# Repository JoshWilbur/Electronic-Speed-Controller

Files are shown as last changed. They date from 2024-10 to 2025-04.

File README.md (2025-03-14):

# Electronic-Speed-Controller

Developers: Amir Seidakhmetov and Joshua Wilbur

This repository contains firmware to drive a 36V Electronic Speed Controller (ESC) for a DC motor. This project has been tested to handle a 3A load without issue. Motor speed is monitored and controlled using a hall effect sensor and PID feedback.

Driver code for the H-Bridge circuit is found in /Core/Src. The files main.c,
H_bridge.c, user_input.c and rpm_feedback.c contain custom code developed
for this project.

Images of the project are found below, along with an operation guide.

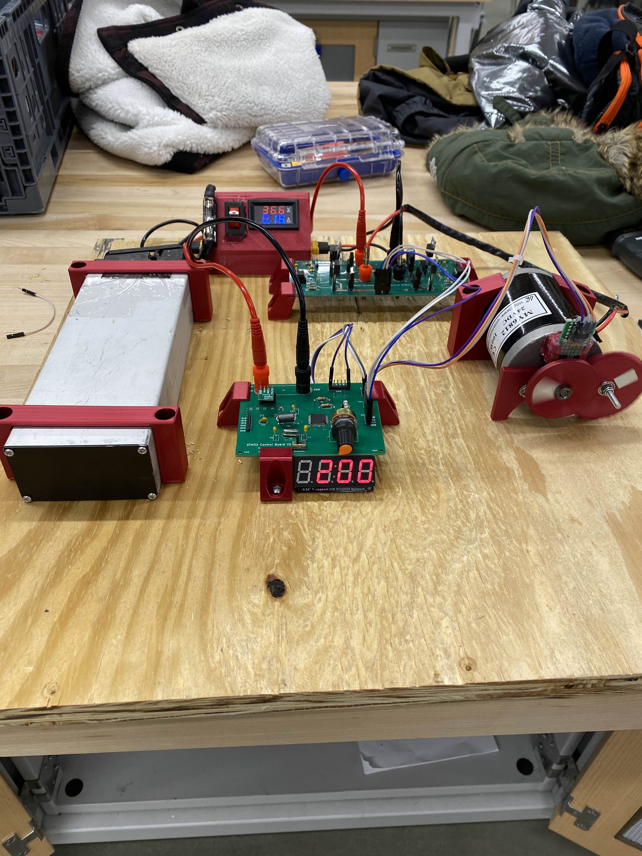
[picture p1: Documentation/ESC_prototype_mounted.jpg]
Prototype December 2024


**Load Testing**
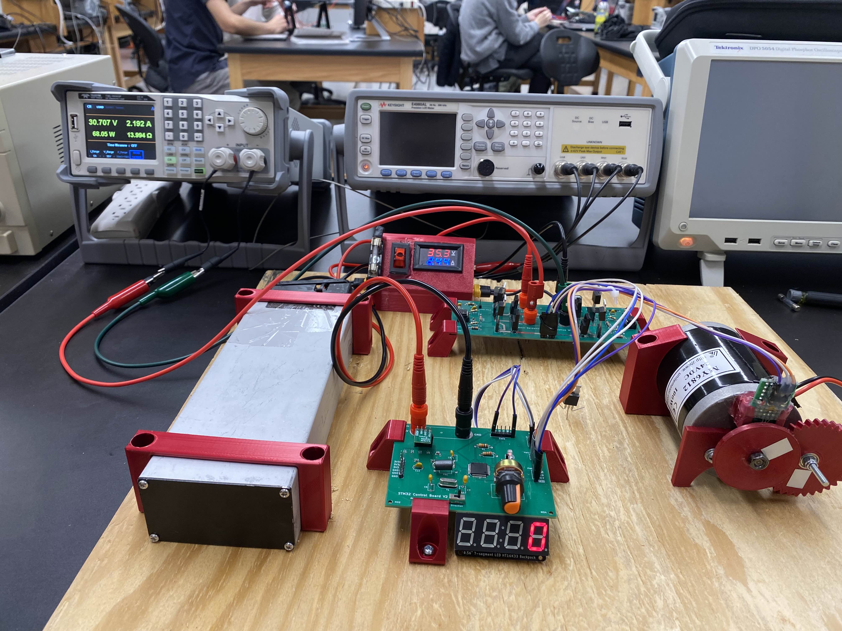
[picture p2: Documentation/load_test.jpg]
Load Test


# Operation Guide

* Construct circuit shown in the latest schematic version with the parts listed in the expense report.
* Optional: Order two PCBs using the files in /H_Bridge_KiCAD and /STM32_KiCAD.
* Program STM32 chip with the code, found in this repository, using SWD.
* Power on circuit and controller.
* For safety, the device starts in an OFF state. Shift the direction switch once to begin operation.
* Use the potentiometer to set a desired speed within the range of 60 to 200 RPM.

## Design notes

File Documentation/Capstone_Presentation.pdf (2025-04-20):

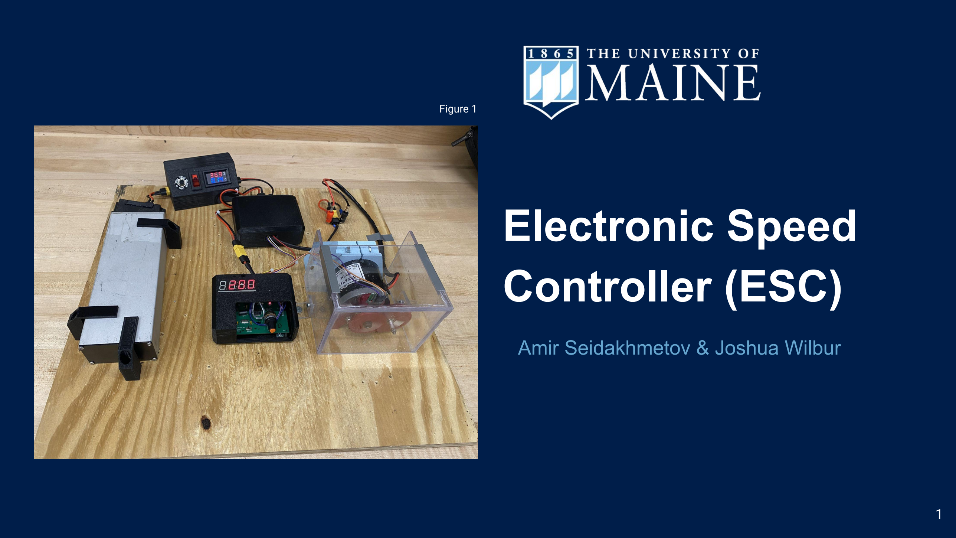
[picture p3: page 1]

# Electronic Speed Controller (ESC)

Amir Seidakhmetov & Joshua Wilbur

Figure 1

# Demonstration

### Presentation Forecast

1. Demonstration
2. Introduction
3. ESC Overview
4. Bootstrap Circuit Design
5. Conclusion
6. Questions

### Purpose of an ESC

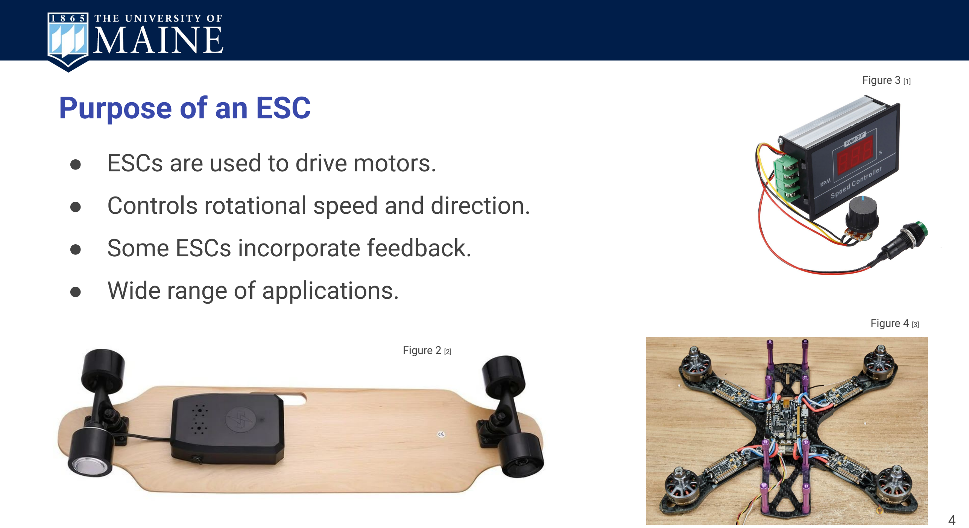
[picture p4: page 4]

- ESCs are used to drive motors.
- Controls rotational speed and direction.
- Some ESCs incorporate feedback.
- Wide range of applications.

Figure 3 [1]

Figure 2 [2]

Figure 4 [3]

### Why Did We Build an ESC?

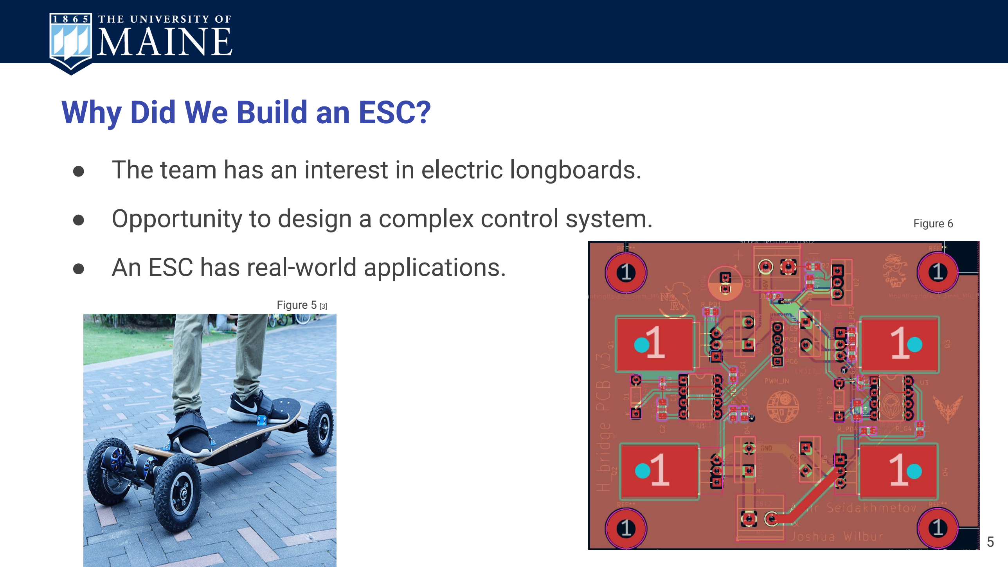
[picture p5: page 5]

- The team has an interest in electric longboards.
- Opportunity to design a complex control system.
- An ESC has real-world applications.

Figure 5 [3]

Figure 6

### Specifications

- H-bridge circuit that can supply at least 2 amps to a motor.
- Closed-loop feedback system to monitor and adjust motor speed.
- Motor rotation speed ranging from 60 RPM ± 5% to 200 RPM ± 5%.

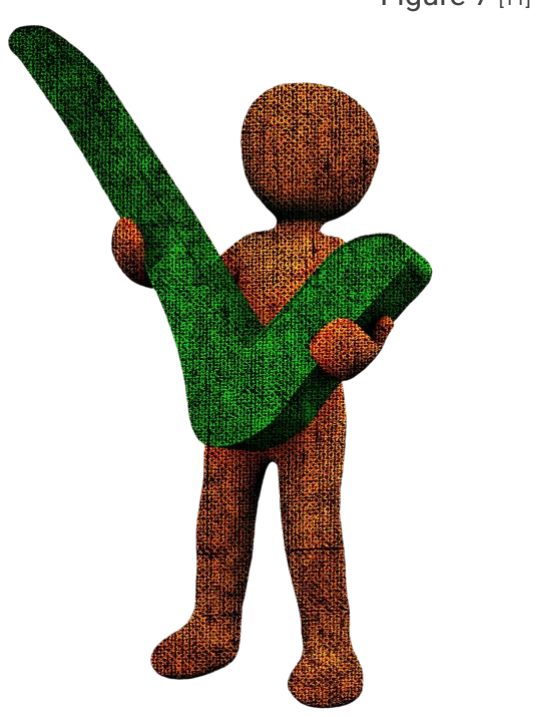
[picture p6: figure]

- Custom PCB designed for the project.
- All specifications were met during design review.

Figure 7 [11]

### Similar Devices

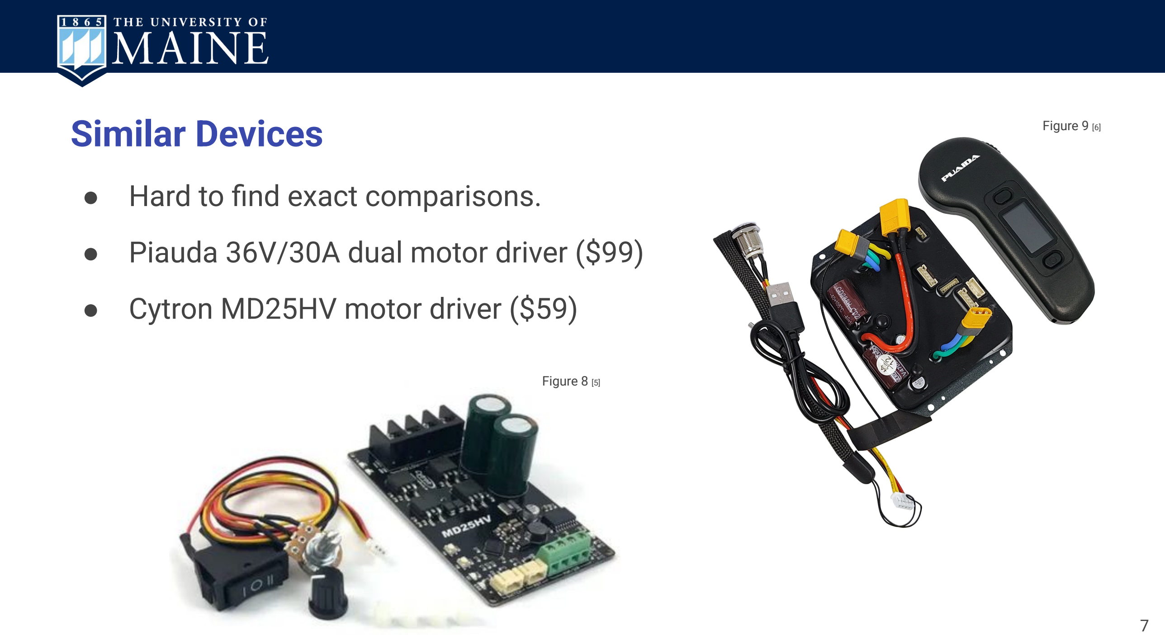
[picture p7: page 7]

- Hard to find exact comparisons.
- Piauda 36V/30A dual motor driver ($99)
- Cytron MD25HV motor driver ($59)

Figure 8 [5]

Figure 9 [6]

# ESC Overview

### Hardware Block Diagram

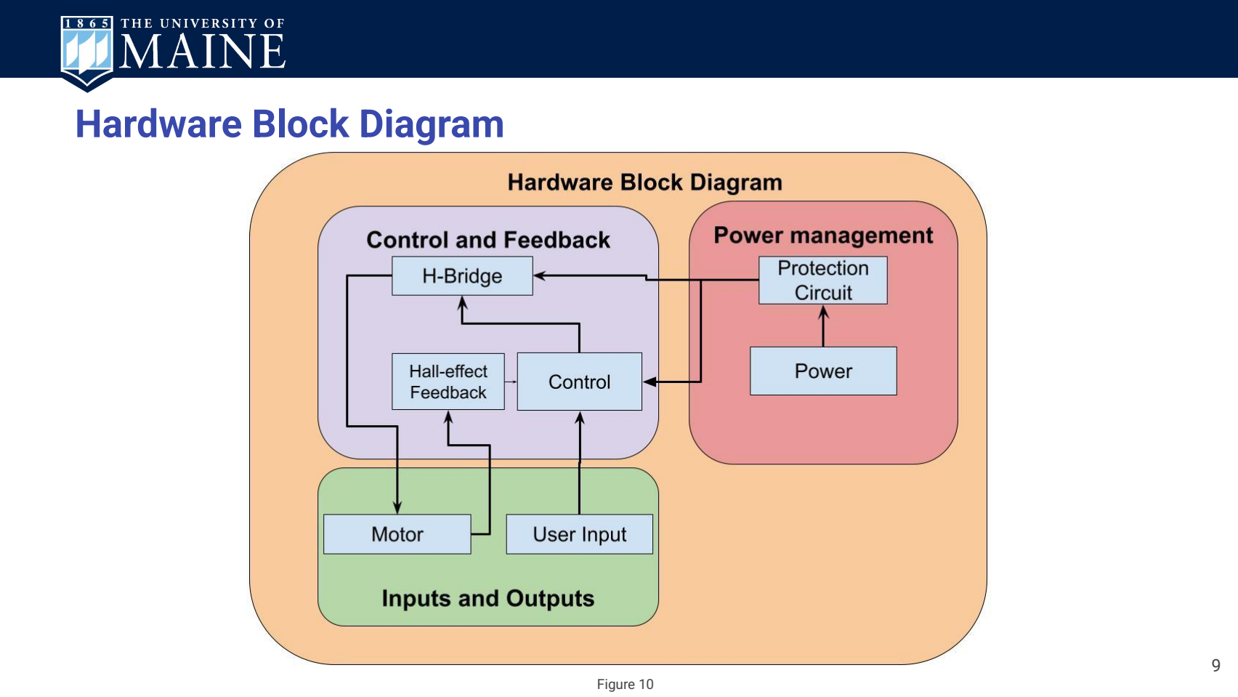
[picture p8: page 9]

Figure 10

### Software Block Diagram

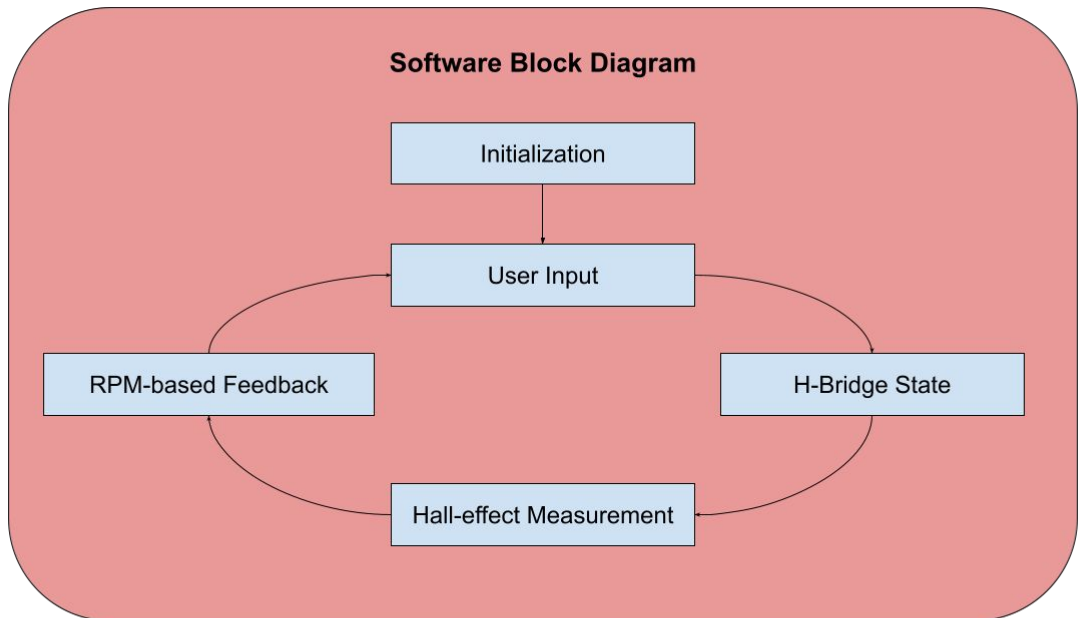
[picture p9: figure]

10 Figure 11

# Bootstrap Circuit Design

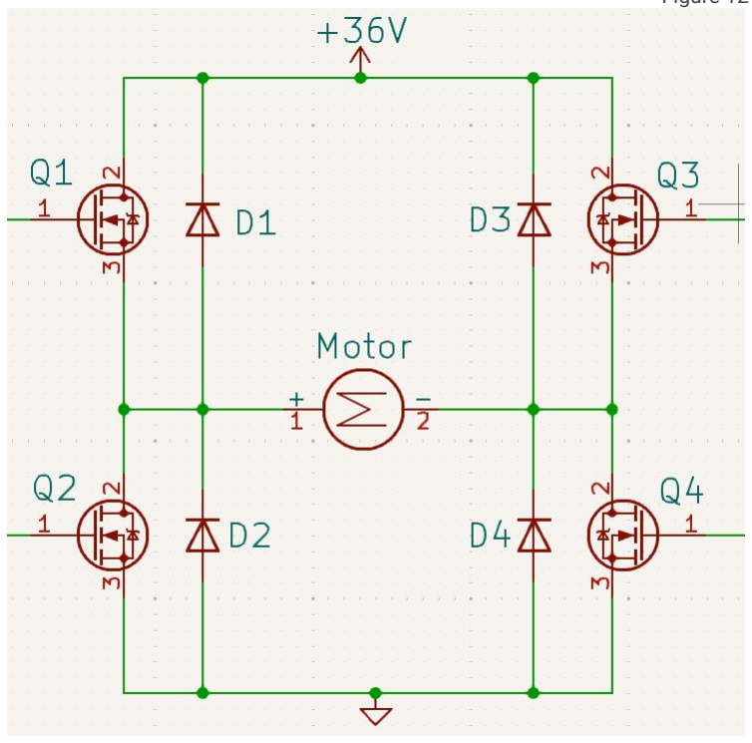
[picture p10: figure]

### Bootstrap Circuit Purpose

- Motor driven by a MOSFET H-bridge.
- MOSFETs require VGS > Vth to turn on
- VDS ≥ (VGS - Vth) for saturation.
- Need a way to boost VG above 36V supply.
- A bootstrap circuit can achieve this.

Figure 12

### Gate Driver Selection

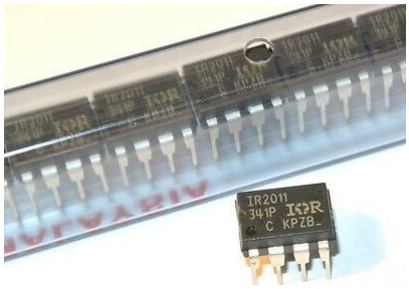
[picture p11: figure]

- Half-bridge driver for N-channel MOSFETs.
- Microcontroller outputs 3.3V signals.
- Gate current requirement.
- IR2011 from Infineon satisfied our needs.

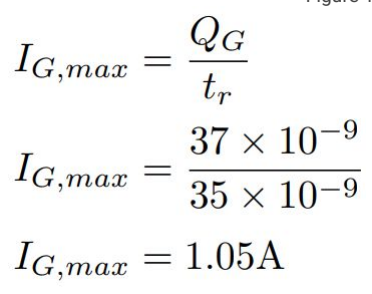
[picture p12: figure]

Figure 13

Figure 14 [7]

### Bootstrap Circuit Components

Figure 15

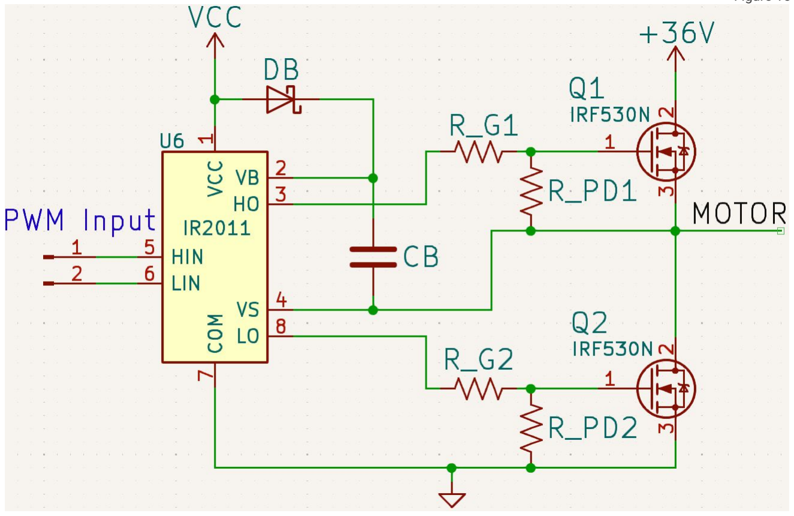
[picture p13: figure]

### Bootstrap Circuit Context

- Gate driver supply voltage (VCC) set to 15V.
- RDS(ON) minimized when VGS is 10V or greater.
- Bootstrap diode: 1N4148

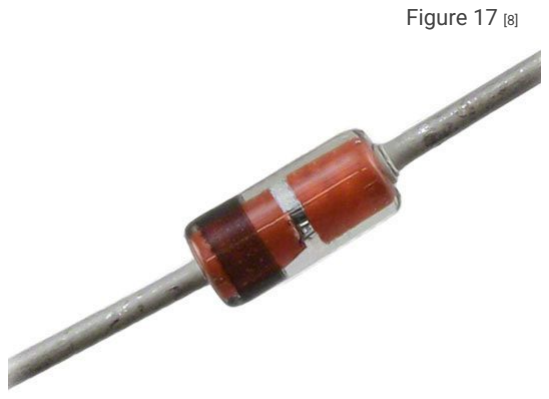
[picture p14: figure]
Figure 17 [8]

- Voltage across CB drops when high-side MOSFET turns on.

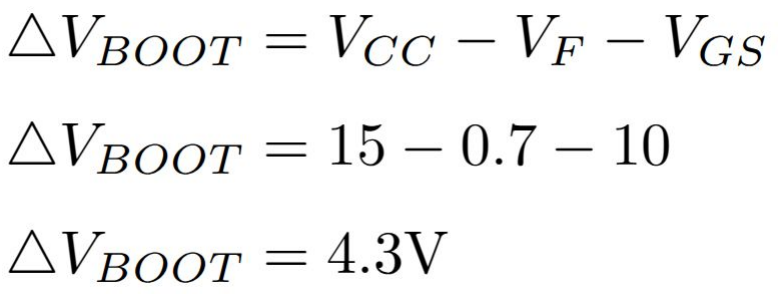
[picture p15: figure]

Figure 16

### Bootstrap Capacitor Calculation

- Value dependant on total charge and allowable voltage drop.

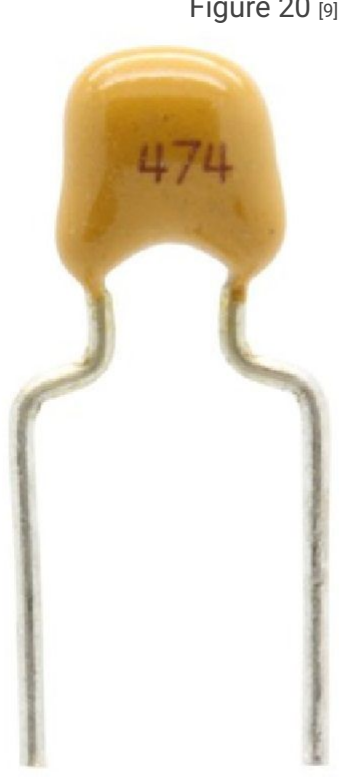
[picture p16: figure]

- Recommended value is at least 10x larger than the minimum.
- The team used a 470nF capacitor.

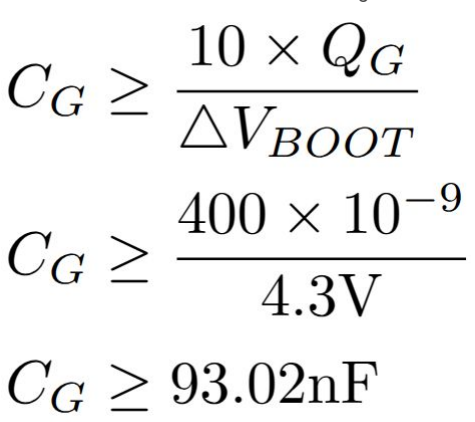
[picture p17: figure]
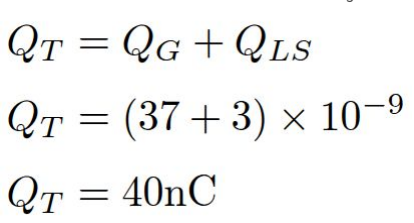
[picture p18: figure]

Figure 18

Figure 19

Figure 20 [9]

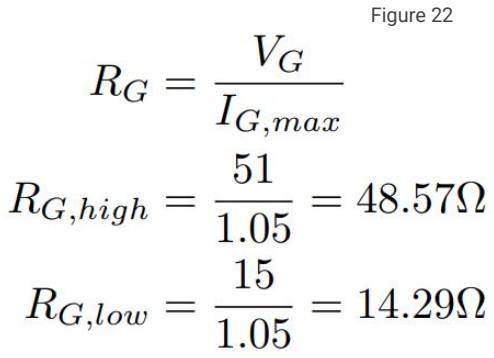
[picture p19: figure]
Figure 22

### Gate Resistor Calculations

- Increased resistance slows switching transition.
- Mitigates ringing in the MOSFET gate.
- High-side gate voltage greater than low-side.

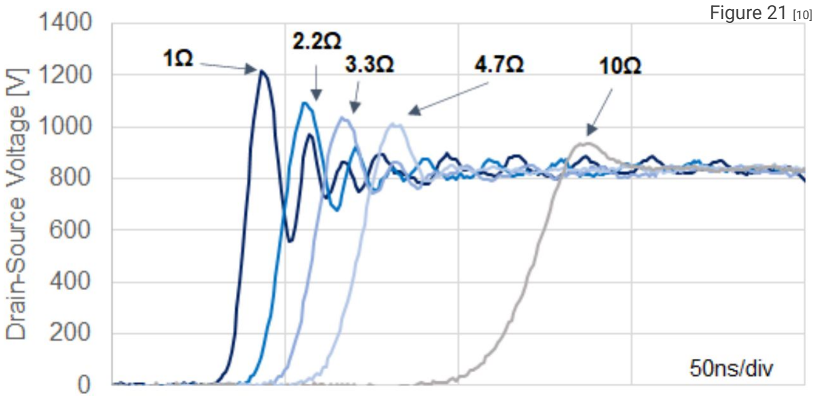
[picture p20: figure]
Figure 21 [10]

### Designed Bootstrap Circuit

Figure 23

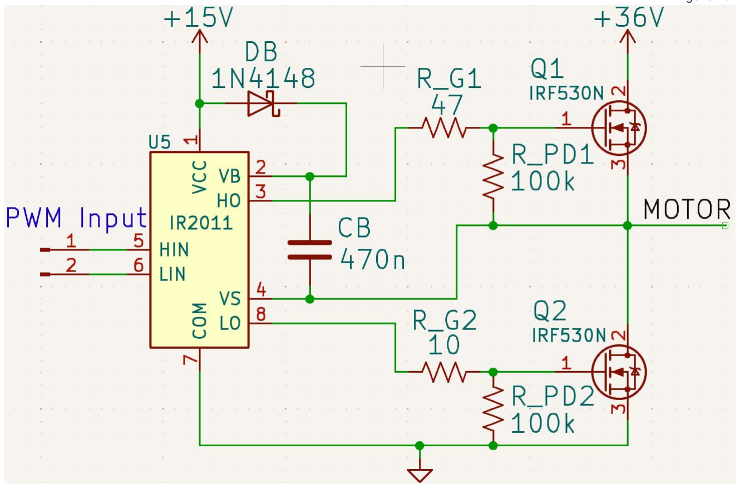
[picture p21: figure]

# Conclusion

### Specifications Testing

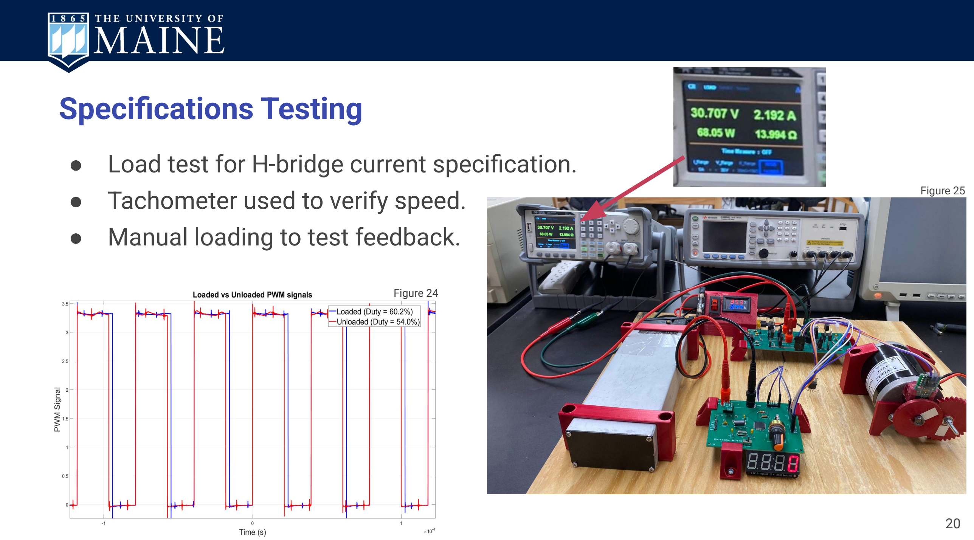
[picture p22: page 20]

- Load test for H-bridge current specification.
- Tachometer used to verify speed.
- Manual loading to test feedback.

Figure 25

Figure 24

### ESC Outcomes

- The designed ESC met the contract and all specifications.
- Average error in speed was 2.27%.
- Speed specification was limiting.
- The team is satisfied with the project outcome.

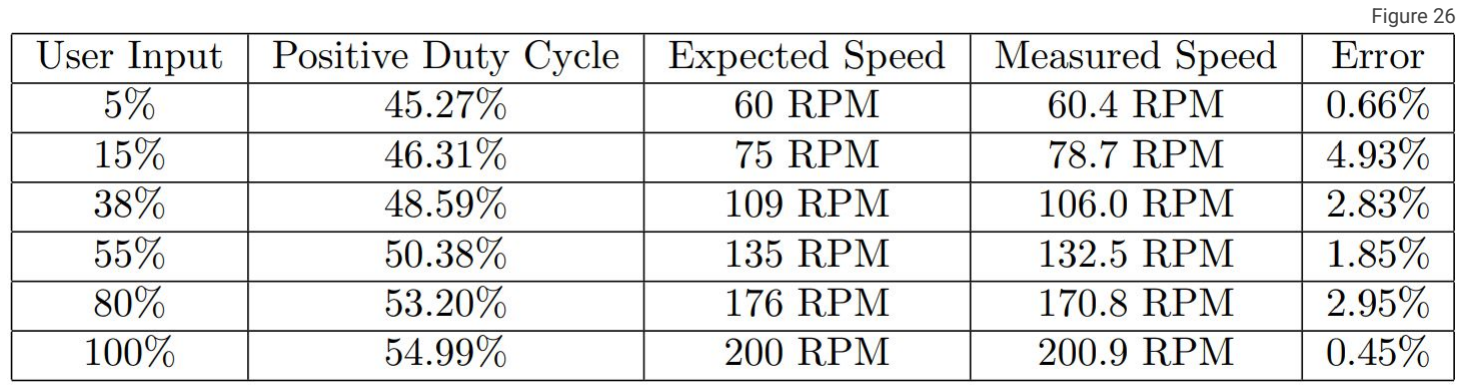
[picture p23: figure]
Figure 26

### Advice to Juniors

- Carefully read through datasheets.
- Use available resources on campus.
- Learn PCB and CAD design.

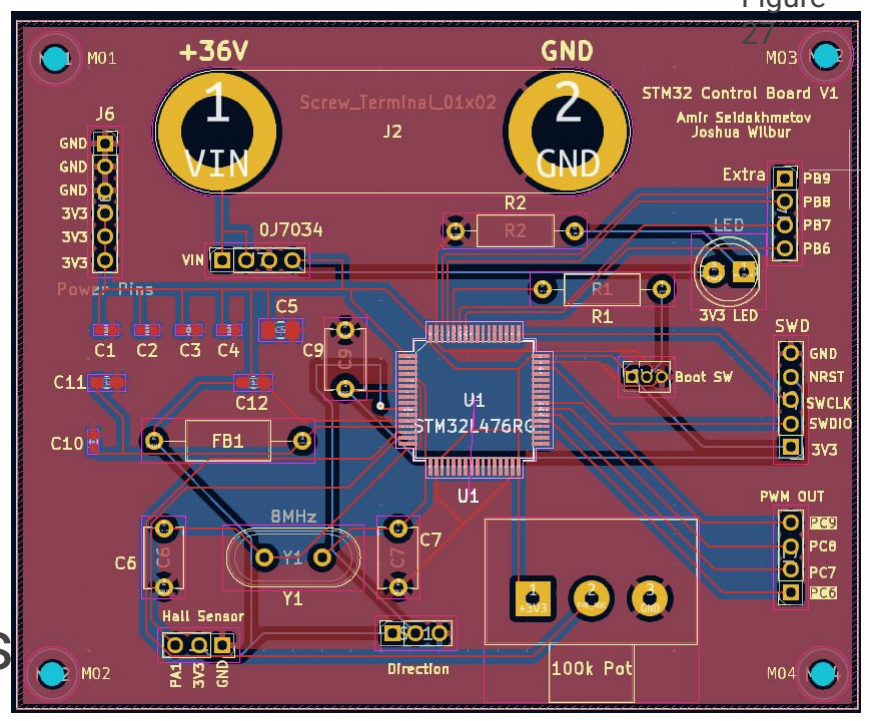
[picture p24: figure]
Figure X

- Don’t doubt yourself too much, but do sanity checks.
- Start early.
- Order extra parts.
- Seek help from professors.

Figure

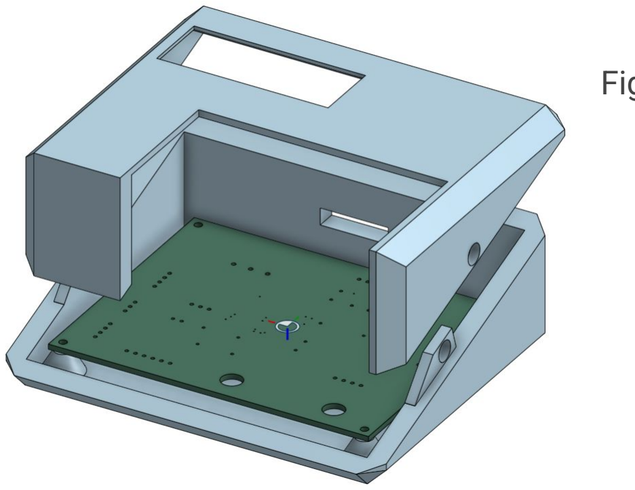
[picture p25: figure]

Figure 28

# Questions

### References

[1] https://cdn.shopify.com/s/files/1/0071/3664/1135/products/3f78b11f-4b91-46de-8d47-90ac765680e1_2048x2048.jpg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
[2] https://i5.walmartimages.com/asr/c25423d8-cd6b-4dfd-a03d-7d6a7bdeda9b_1.c19fde99052ac520eedd921e9d779c17.jpeg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
[3] https://oscarliang.com/ctt/uploads/2017/12/how-to-build-fpv-mini-quad-racing-drone-solder-esc-to-fc.jpg
[4] https://supplyleader.com/preview_files/165.jpg
[5] https://www.robotshop.com/products/cytron-25a-7-58v-single-brushed-dc-motor-driver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
[6] https://www.puaida.com/cdn/shop/files/20240509152312_1024x1024@2x.jpg?v=1715240759
[7] https://i.ebayimg.com/images/g/H4wAAOSwPhdU8hiP/s-l400.jpg
[8] https://mm.digikey.com/Volume0/opasdata/d220001/medias/images/649/1N5229BFS.jpg
[9] https://megatronica.cc/wp-content/uploads/2022/04/db25-22.jpg
[10] https://fscdn.rohm.com/en/products/databook/applinote/discrete/sic/mosfet/gate_drive_circuit-design_guidelines_an-e.pdf
[11] https://pixabay.com/photos/successful-consent-check-mark-hook-2633707/

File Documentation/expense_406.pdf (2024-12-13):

# Electronic Speed Controller

### Amir Seidakhmetov (EE) Joshua Wilbur (CE)

### December 8th, 2024

# Expense Report

Line | Vendor | Quantity | Vendor Part Number | Description | Unit Price | Extended Price
1 | Amazon | 1 | MY6812 (https://www.amazon.com/dp/B01MTDKNF8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) | 100W 24VDC Brushed Motor | $36.99 | $36.99
2 | Battery Hookup | 1 | GNS6 (https://batteryhookup.com/products/36v-5-2ah-187-2wh-lithium-ion-ebike-battery-with-bms) | 36V/5.2Ah Lithium Ion E-bike battery | $22.00 | $22.00
3 | Jameco | 1 | 2355231 (https://www.jameco.com/z/DSN-VC288-Jameco-ValuePro-High-Quality-DC-100V-10A-Voltmeter-Ammeter-Blue-Red-LED-Amp-Dual-Digital-Volt-Meter-Gauge_2355231.html) | DSM-VC288 Voltage/Amp meter | $4.95 | $4.95
4 | Digikey | 20 | IRF530NPBF-ND (https://www.digikey.com/en/products/detail/infineon-technologies/IRF530NPBF/811762) | N channel MOSFET 100V/17A | $1.42 | $28.40
5 | Digikey | 14 | IR2011PBF-N D (https://www.digikey.com/en/products/detail/infineon-technologies/IR2011PBF/1928081) | MOSFET gate driver IC | $2.785 | $38.99
6 | Digikey | 10 | 497-19621-ND (https://www.digikey.com/en/products/detail/stmicroelectronics/LM317BT/5308099) | Linear voltage regulator 1.5A | $0.411 | $4.11
7 | Mouser | 10 | MBRF10200 (https://www.mouser.com/ProductDetail/821-MBRF10200) | 200V/10A Schottky diode | $0.809 | $8.09
8 | Digikey | 10 | 1N4148FS-ND (https://www.digikey.com/en/products/detail/onsemi/1N4148/458603) | 1N4148 small signal diode | $0.055 | $0.55
9 | Mouser | 10 | 232-50ZLH10 0MEFC8X15 (https://www.mouser.com/ProductDetail/Rubycon/50ZLH100MEFC8X11.5) | 50V, 100uF electrolytic radial capacitor | $0.125 | $1.25
10 | Digikey | 10 | C323C200KA G5TA-ND (https://www.digikey.com/en/products/detail/kemet/C323C200KAG5TA/6656893) | 20pF ceramic radial capacitor, +/-10% | $0.241 | $2.41
11 | Digikey | 10 | 399-9793-ND (https://www.digikey.com/en/products/detail/kemet/C322C103KDR5TA/3726051) | 0.01uF ceramic radial capacitor, +/-10% | $0.786 | $7.86
12 | Digikey | 20 | 1276-6720-1-ND (https://www.digikey.com/en/products/detail/samsung-electro-mechanics/CL05B104KA5NNNC/5961204) | 0.1uF ceramic 0402 capacitor, +/-10% | $0.006 | $0.12
13 | Digikey | 50 | 399-4331-ND (https://www.digikey.com/en/products/detail/kemet/C322C104M5U5TA/818107) | 0.1uF ceramic radial capacitor, +/-20% | $0.181 | $9.07
14 | Digikey | 10 | 399-13979-1-ND (https://www.digikey.com/en/products/detail/kemet/C320C474M5U5TA7301/6562390) | 0.47uF ceramic radial capacitor, +/-20% | $0.297 | $2.97
15 | Digikey | 10 | 1276-1102-1-ND (https://www.digikey.com/en/products/detail/samsung-electro-mechanics/CL10A105KA8NNNC/3886760) | 1uF ceramic 0402 capacitor, +/-10% | $0.012 | $0.12

16 | Digikey | 10 | 1276-1244-1-ND (https://www.digikey.com/en/products/detail/samsung-electro-mechanics/CL21A475KAQNNNE/3886902) | 4.7uF ceramic 0805 capacitor, +/-10% | $0.057 | $0.57
17 | Digikey | 50 | 13-CFR-25JR-52-10RCT-ND (https://www.digikey.com/en/products/detail/yageo/CFR-25JR-52-10R/11926) | 1/4W 10 Ohm 5% resistor, axial | $0.027 | $1.33
18 | Digikey | 50 | 13-CFR-25JR-52-47RCT-ND (https://www.digikey.com/en/products/detail/yageo/CFR-25JR-52-47R/11942) | 1/4W 47 Ohm 5% resistor, axial | $0.027 | $1.33
19 | Digikey | 50 | CF14JT470R CT-ND (https://www.digikey.com/en/products/detail/stackpole-electronics-inc/CF14JT470R/1741440) | 1/4W 470 Ohm 5% resistor, axial | $0.023 | $1.16
20 | ECE Dept. | 3 | N/A | 1/4W 2.2k Ohm 5% resistor, axial | $0.00 | $0.00
21 | Digikey | 50 | CF14JT5K60 CT-ND (https://www.digikey.com/en/products/detail/stackpole-electronics-inc/CF14JT5K60/1741453) | 1/4W 5.6k Ohm 5% resistor, axial | $0.023 | $1.16
22 | ECE Dept. | 3 | N/A | 1/4W 10k Ohm 5% resistor, axial | $0.00 | $0.00
23 | Hackerspace | 3 | N/A | 100k Ohm potentiometer | $0.00 | $0.00
24 | ECE Dept. | 2 | N/A | Red LED, radial package | $0.00 | $0.00
25 | Digikey | 3 | 732-13783-ND (https://www.digikey.com/en/products/detail/w%C3%BCrth-elektronik/7427502/10058998) | Ferrite bead, 976 Ohm @ 100MHz | $0.50 | $1.50
26 | Digikey | 3 | 50-ECS-80-18 -4X-CKM-ND (https://www.digikey.com/en/products/detail/ecs-inc/ECS-80-18-4X-CKM/12349411) | 8MHz Crystal Oscillator, 2 pin | $0.42 | $1.26
27 | Digikey | 6 | 296-40063-1-ND (https://www.digikey.com/en/products/detail/texas-instruments/DRV5053PAQLPGMQ1/5140759) | Hall effect sensor, TO-92-3 package | $0.634 | $3.80
28 | Digikey | 8 | 6236BG-ND (https://www.digikey.com/en/products/detail/boyd-laconia-llc/6236BG/1624948) | TO-220 heatsink with clip | $2.94 | $23.52
29 | Digikey | 25 | 2057-ICS-308-T-ND (https://www.digikey.com/en/products/detail/adam-tech/ICS-308-T/9829299) | 8 pin DIP IC socket | $0.086 | $2.16
30 | Digikey | 1 | 2183-2106-ND (https://www.digikey.com/en/products/detail/pololu-corporation/2106/10451130) | DC DC Converter, 36V input, 3.3V output | $6.95 | $6.95
31 | Adafruit | 5 | 805 (https://www.adafruit.com/product/805) | SPDT breadboard-friendly slide switch | $0.95 | $4.75
32 | Digikey | 6 | 497-17992-ND (https://www.digikey.com/en/products/detail/stmicroelectronics/STM32L476RGT3/8257940) | STM32L476RGT3 surface mount chip | $8.61 | $51.66
33 | Amazon | 1 | RM-6X3-100P (https://www.amazon.com/gp/product/B09MRN2X7L/ref=ppx_yo_dt_b_search_asin_title?ie=UTF8&psc=1) | 100ct 6x3MM magnets | $7.99 | $7.99
34 | Amazon | 1 | S36 (https://www.amazon.com/dp/B07NM68FXK?ref=ppx_yo2ov_dt_b_fed_asin_title) | Smraza 30ct solder board kit with pin headers and sockets | $13.99 | $13.99
35 | Digikey | 3 | 501-1080-ND (https://www.digikey.com/en/products/detail/pomona-electronics/1581-2/603387) | Female banana plug, red | $2.56 | $7.68
36 | Digikey | 3 | 501-1078-ND (https://www.digikey.com/en/products/detail/pomona-electronics/1581-0/603385) | Female banana plug, black | $2.56 | $7.68

3 7 | J L C P C B | 1 | N /A | 9 4 m m x 7 4.3 m m P C B, 1 o z c o p p e r | $ 2.0 0 | $ 2.0 0
3 8 | J L C P C B | 1 | N /A | 1 5 9.5 m m x 6 2.5 m m P C B, 2 o z c o p p e r | $ 2 5.1 0 | $ 2 5.1 0
| | | | T O TA L C O S T : | | $ 3 3 3.4 7

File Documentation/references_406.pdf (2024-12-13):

## Electronic Speed Controller References

Amir Seidakhmetov (EE)
Joshua Wilbur (CE)

December 12th, 2024

Application Notes
- Renesas AN1325: “Choosing and Using Bypass Capacitors” (https://www.renesas.com/en/document/apn/an1325-choosing-and-using-bypass-capacitors)
- Fairchild AN-6076: “Design and Application Guide of Bootstrap Circuit…” (https://web.eecs.utk.edu/~dcostine/ECE482/Spring2017/materials/AN-6076.pdf)
- TI: “Bootstrap Circuitry Selection for Half-Bridge Configurations” (https://www.ti.com/lit/an/slua887a/slua887a.pdf?ts=1717921338527)
- TI: “Fundamentals of MOSFET and IGBT Gate Driver Circuits” (https://www.ti.com/lit/ml/slua618a/slua618a.pdf?ts=1710846540538)
- Toshiba: “MOSFET Gate Drive Circuit Application Note” (https://toshiba.semicon-storage.com/info/application_note_en_20180726_AKX00068.pdf?did=59460)
- ST AN2867: “Guidelines for oscillator design on STM32 MCUs” (https://www.st.com/resource/en/application_note/cd00221665-oscillator-design-guide-for-stm8af-al-s-stm32-mcus-and-mpus-stmicroelectronics.pdf)
- Analog MT-101: “Decoupling Techniques” (https://www.analog.com/media/en/training-seminars/tutorials/MT-101.pdf)
- International Rectifier AN-978: “HV Floating MOS-Gate Driver ICs” (https://www.farnell.com/datasheets/2254418.pdf)
- ST AN4555: “Getting started with STM32L4 Series hardware development” (https://www.st.com/resource/en/application_note/an4555-getting-started-with-stm32l4-series-and-stm32l4-series-hardware-development-stmicroelectronics.pdf)
- ST: STM32L476xx Datasheet (https://www.digikey.com/en/products/detail/stmicroelectronics/STM32L476RGT3/8257940)

Reference Circuits
- Northwestern: “Driving a high current DC motor using an H-Bridge” (https://hades.mech.northwestern.edu/index.php/Driving_a_high_current_DC_Motor_using_an_H-bridge)
- Universitas Negeri Semarang: “Design of Brushless DC Motor Driver…” (https://www.researchgate.net/publication/377088092_Design_of_Brushless_DC_Motor_Driver_Based_on_Bootstrap_Circuit)
- Altium: “100A 12V H-Bridge Project” (https://resources.altium.com/p/100a-12v-h-bridge-project)
- Phil’s Lab: KiCAD 6 STM32 PCB Design Tutorial (https://www.youtube.com/watch?v=aVUqaB0IMh4)

General Information
- Modular Circuits: H-Bridge Secrets (https://www.modularcircuits.com/blog/articles/h-bridge-secrets/)
- Analog: Reverse-Current Circuitry Protection (https://www.analog.com/en/resources/design-notes/reversecurrent-circuitry-protection.html)
- Digikey: Getting started with STM32… (https://www.digikey.com/en/maker/projects/getting-started-with-stm32-introduction-to-stm32cubeide/6a6c60a670c447abb90fd0fd78008697)
- ST UM2609: “STM32CubeIDE user guide” (https://www.st.com/resource/en/user_manual/um2609-stm32cubeide-user-guide-stmicroelectronics.pdf)
- Power MOSFET selection and application (https://www.youtube.com/watch?v=56p3_aORiJ0) (video)
- Why gate drivers are needed (https://www.youtube.com/watch?v=8swJ_Bnsgl4) (video)

Miscellaneous
- Gannt Chart: | Capstone Schedule (https://docs.google.com/spreadsheets/u/2/d/1QXNZ29SJuQbADEKK193B_FxKowuRFFEij1yh2T8SVlU/edit#gid=0)
- Part order spreadsheet: | Seidakhmetov-Wilbur-Digikey-1 (https://docs.google.com/spreadsheets/d/1-iv_heHPHUjrlUgwJe5SL9CYelO3otoqwrFYjtWU_Qw/edit?gid=0#gid=0)
- GitHub repository: https://github.com/JoshWilbur/Electronic-Speed-Controller
- Battery powered STM32 PCB (https://embeddedprojects101.com/design-a-battery-powered-stm32-board-with-usb/)
- Voltage regulator overheating thread (https://electronics.stackexchange.com/questions/18478/my-linear-voltage-regulator-is-overheating-very-fast)

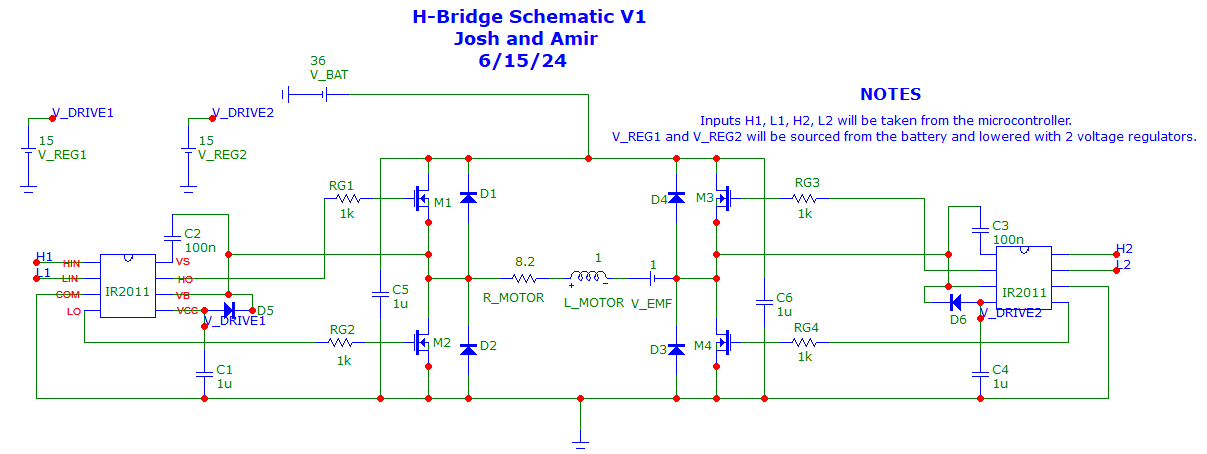
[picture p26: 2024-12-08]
Schematics/H_Bridge_SchematicV1.png

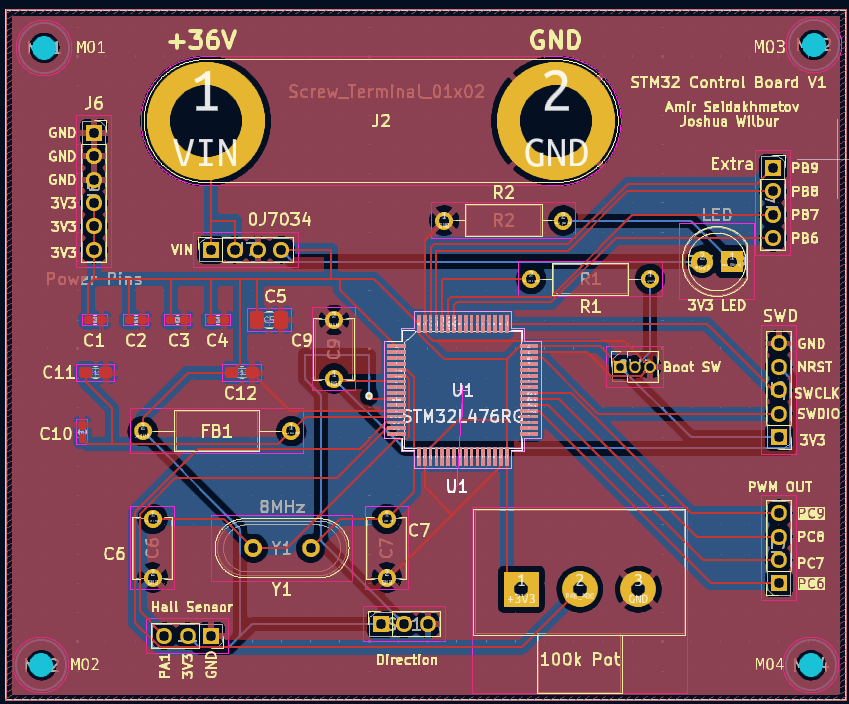
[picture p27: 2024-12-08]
STM32_KiCAD/STM32_controlV1_picture.png

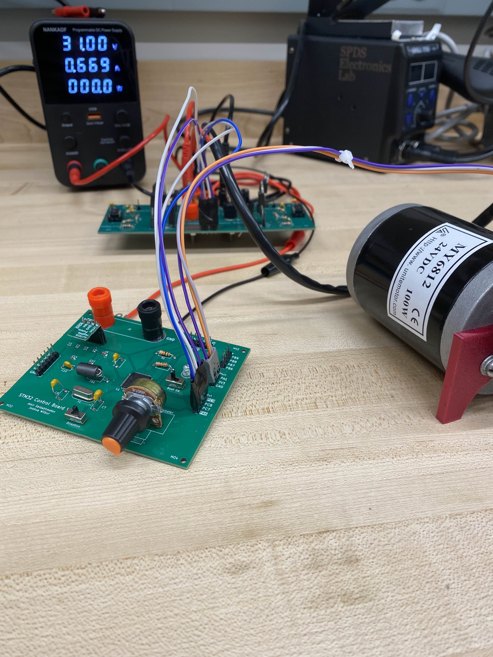
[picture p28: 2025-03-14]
Documentation/ESC_prototype.jpg

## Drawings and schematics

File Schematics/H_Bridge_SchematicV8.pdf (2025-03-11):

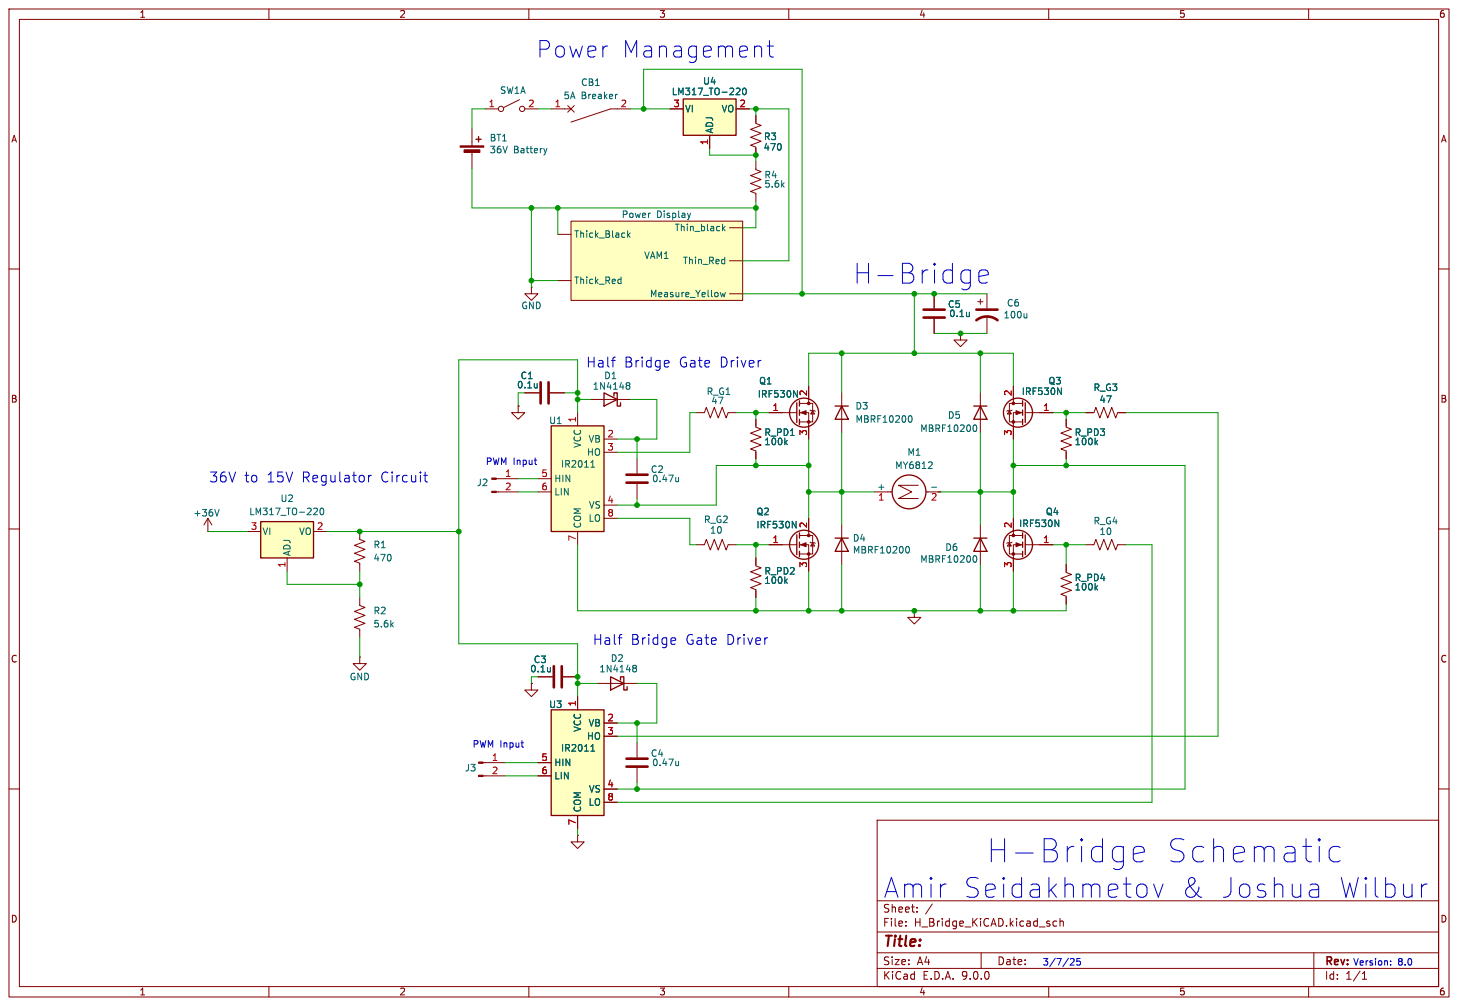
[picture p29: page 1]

Half Bridge Gate Driver
PWM Input

Id: 1/1 Title: File: H_Bridge_KiCAD.kicad_sch Sheet: /

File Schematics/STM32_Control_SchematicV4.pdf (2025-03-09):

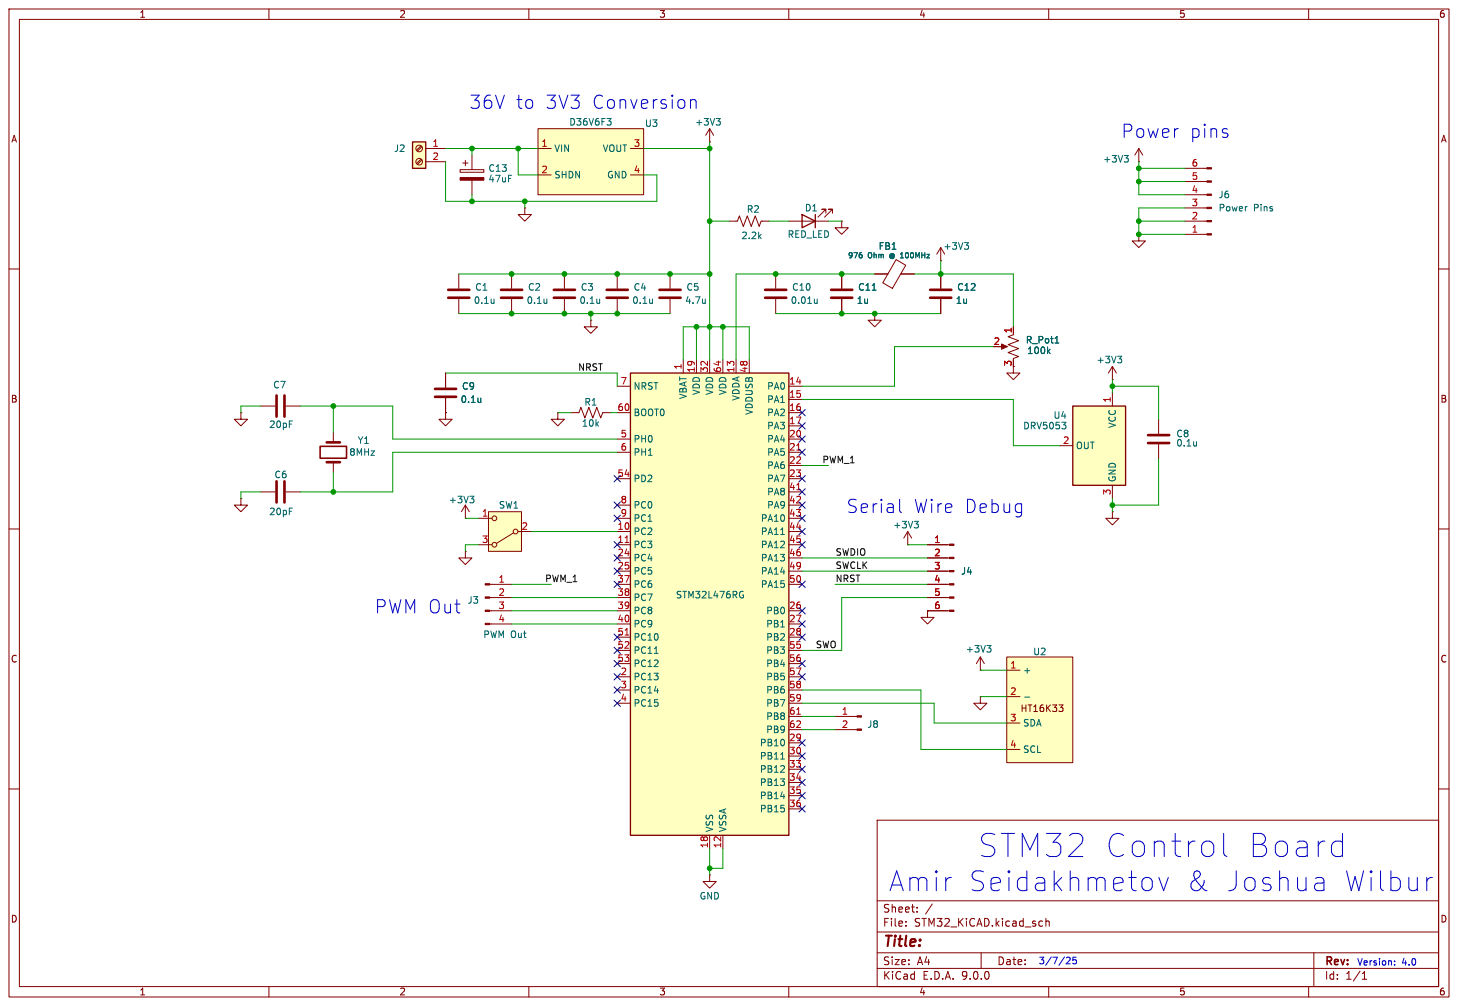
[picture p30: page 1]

1 VDD 19 VDD 32 VSS 18 VDD 64 VSSA 12 VDDA 13 VDDUSB 48 PA0 14 PA1 15 PA2 16 PA3 17 PA4 20 PA5 21 PA6 22 PA7 23 PA8 41 PA9 42 PA10 43 PA11 44 PA12 45 PA13 46 PA14 49 PA15 50 PB0 26 PB1 27 PB2 28 PB3 55 PB4 56 PB5 57 PB6 58 PB7 59 PB8 61 PB9 62 PB10 29 PB11 30 PB12 33 PB13 34 PB14 35 PB15 36 STM32L476RG

Id: 1/1 Title: File: STM32_KiCAD.kicad_sch Sheet: /

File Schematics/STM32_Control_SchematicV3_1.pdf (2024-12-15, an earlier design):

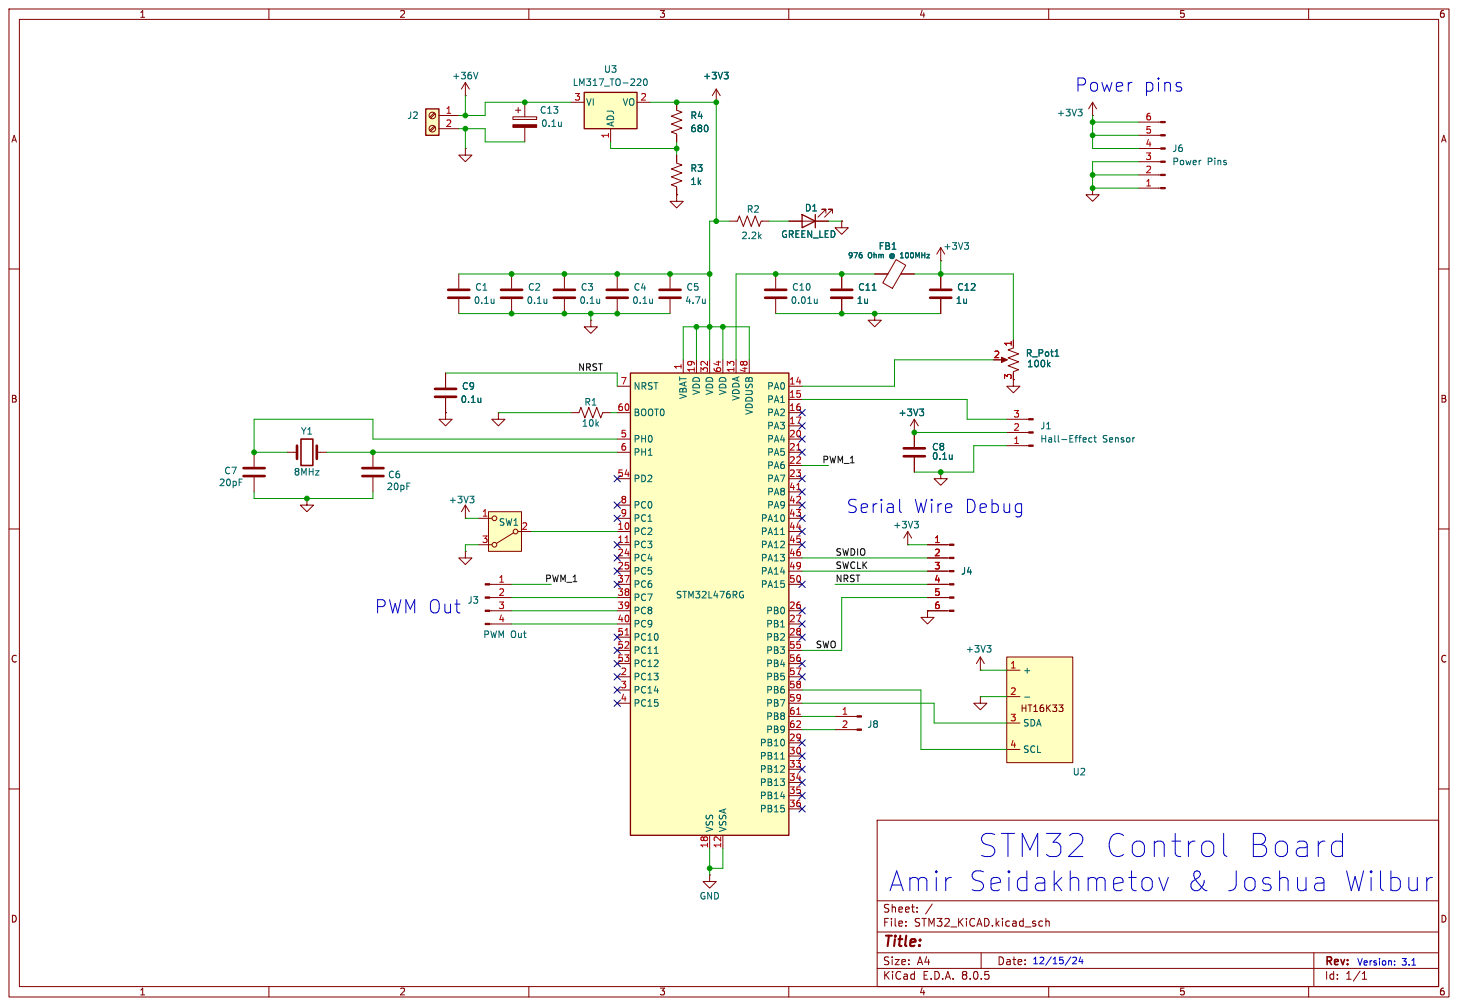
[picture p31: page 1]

1 PC2 10 PC3 11 VSSA 12 VDDA 13 PA0 14 PA1 15 PA2 16 PA3 17 VSS 18 VDD 19 PC13 2 PA4 20 PA5 21 PA6 22 PA7 23 PC4 24 PC5 25 PB0 26 PB1 27 PB2 28 PB10 29 PC14 3 PB11 30 VDD 32 PB12 33 PB13 34 PB14 35 PB15 36 PC6 37 PC7 38 PC8 39 PC15 4 PC9 40 PA8 41 PA9 42 PA10 43 PA11 44 PA12 45 PA13 46 VDDUSB 48 PA14 49 PH0 5 PA15 50 PC10 51 PC11 52 PC12 53 PD2 54 PB3 55 PB4 56 PB5 57 PB6 58 PB7 59 PH1 6 BOOT0 60 PB8 61 PB9 62 VDD 64 NRST 7 PC0 8 PC1 9 STM32L476RG

PWM_1 SWCLK NRST SWO PWM Out

Id: 1/1 Title: File: STM32_KiCAD.kicad_sch Sheet: /

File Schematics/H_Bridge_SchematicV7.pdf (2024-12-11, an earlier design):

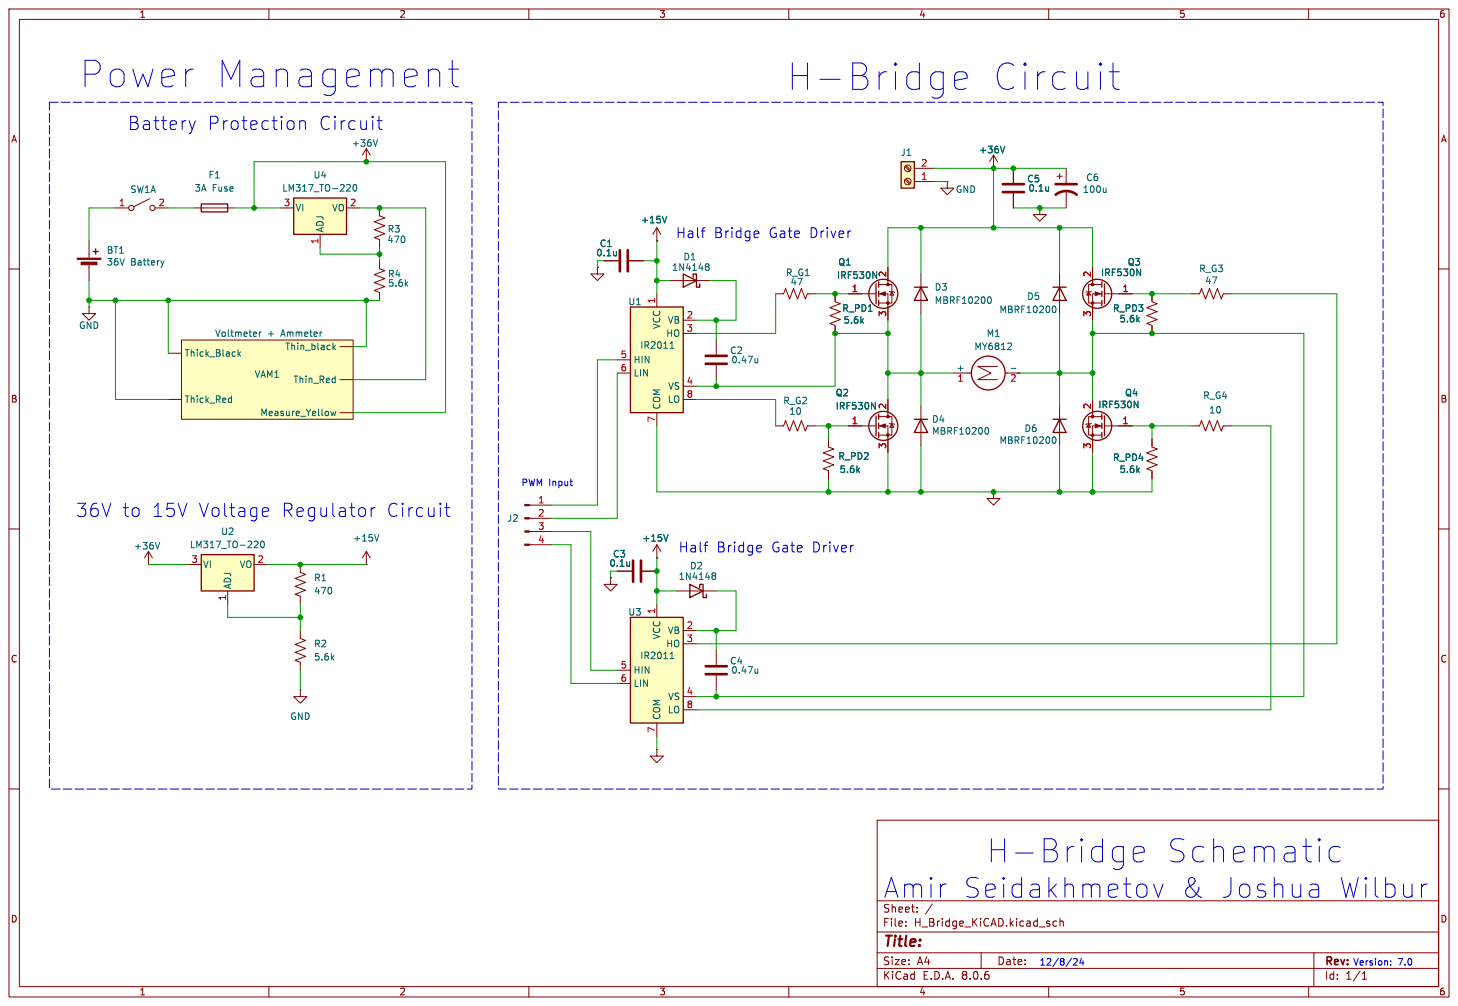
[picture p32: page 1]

Half Bridge Gate Driver

1 VB 2 HO 3 VS 4 HIN 5

12/8/24 36V to 15V Voltage Regulator Circuit

Id: 1/1 Title: File: H_Bridge_KiCAD.kicad_sch Sheet: / GND

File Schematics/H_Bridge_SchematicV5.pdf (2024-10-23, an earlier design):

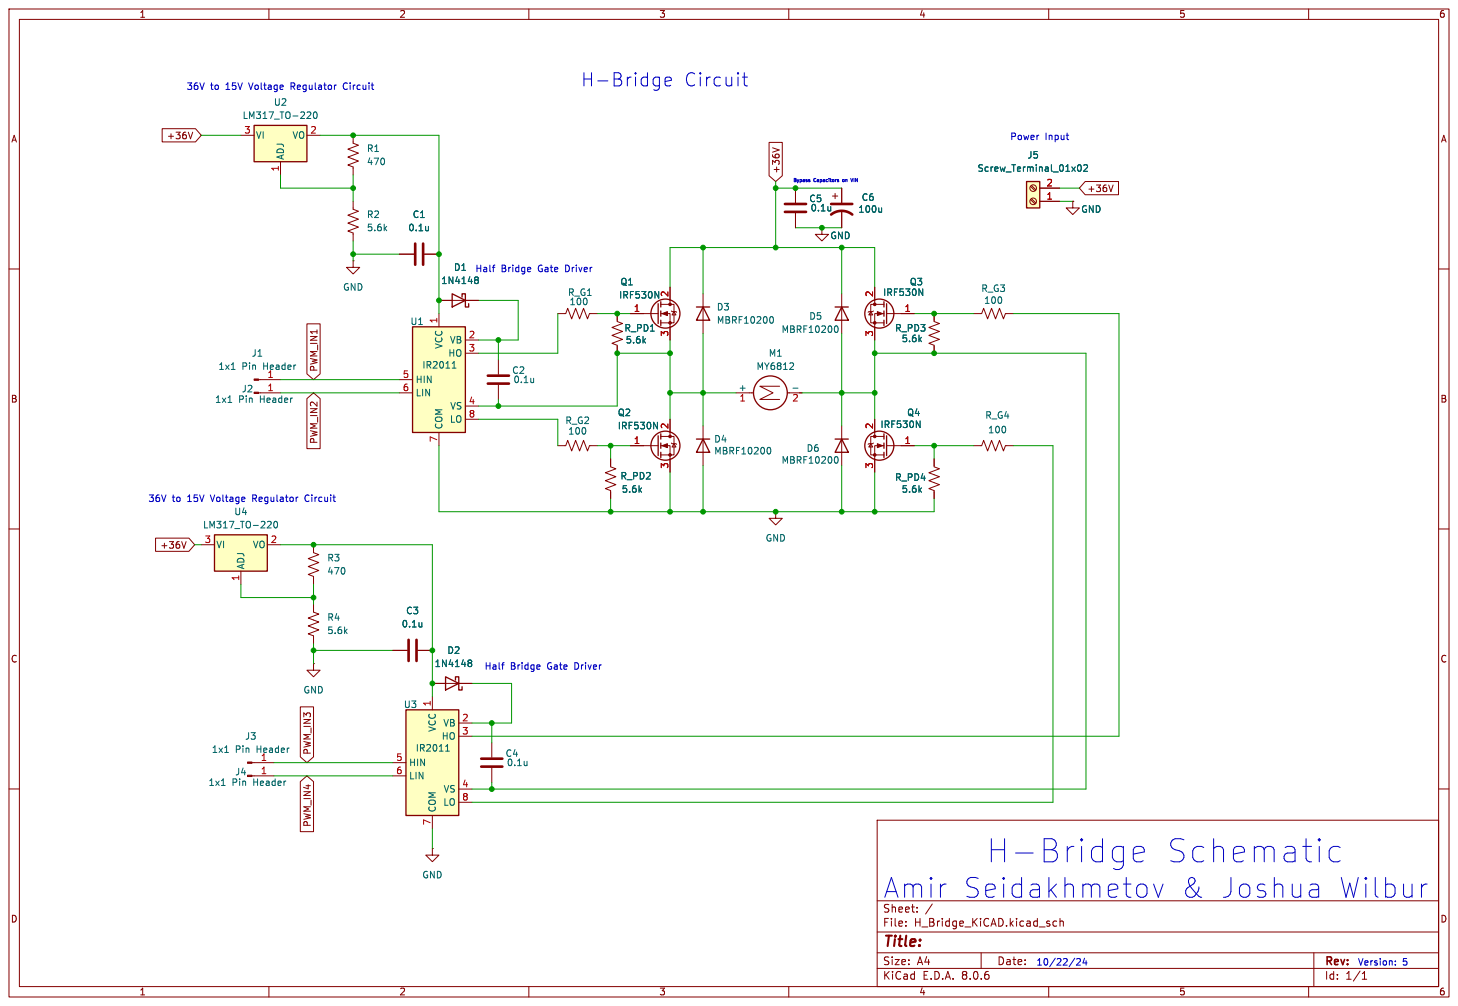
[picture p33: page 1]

1 VB 2 HO 3 VS 4 HIN 5
0.1u VCC

Id: 1/1 Title: File: H_Bridge_KiCAD.kicad_sch Sheet: / D2

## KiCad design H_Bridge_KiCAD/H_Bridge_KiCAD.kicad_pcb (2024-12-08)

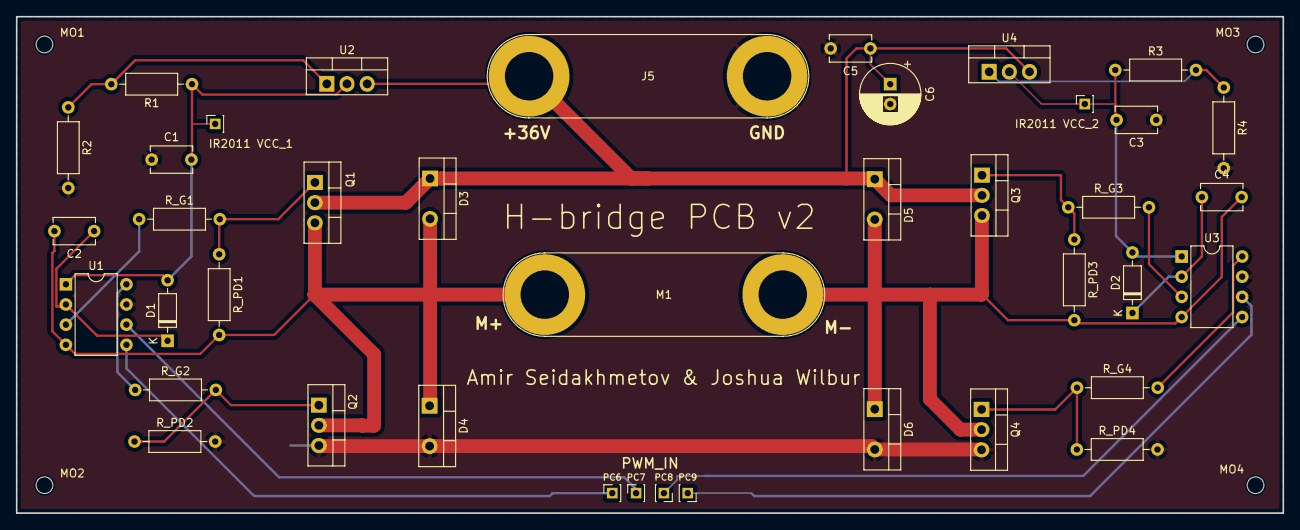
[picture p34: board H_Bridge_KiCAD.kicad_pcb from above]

Board: 2 copper layers, 159.5 x 62.5 mm, 44 parts (0 on the bottom side), 22 nets.

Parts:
C1, C2, C3, C4, C5: 0.1u; C_Disc_D5.1mm_W3.2mm_P5.00mm
C6: 100u; CP_Radial_D7.5mm_P2.50mm
D1, D2: 1N4148; D_DO-35_SOD27_P7.62mm_Horizontal
D3, D4, D5, D6: MBRF10200; TO-220-2_Vertical
IR2011 VCC_1, IR2011 VCC_2: PinSocket_1x01_P2.00mm_Vertical
J5: Screw_Terminal_01x02; Banana_Jack_2Pin
M1: MY6812; Banana_Jack_2Pin
MO1, MO2, MO3, MO4: MountingHole; MountingHole_2.1mm
PC6, PC7, PC8, PC9: 1x1 Pin Header; PinSocket_1x01_P2.00mm_Vertical
Q1, Q2, Q3, Q4: IRF530N; TO-220-3_Vertical
R1, R3: 470; R_Axial_DIN0207_L6.3mm_D2.5mm_P10.16mm_Horizontal
R2, R4: 5.6k; R_Axial_DIN0207_L6.3mm_D2.5mm_P10.16mm_Horizontal
R_G1, R_G2, R_G3, R_G4: 100; R_Axial_DIN0207_L6.3mm_D2.5mm_P10.16mm_Horizontal
R_PD1, R_PD2, R_PD3, R_PD4: 5.6k; R_Axial_DIN0207_L6.3mm_D2.5mm_P10.16mm_Horizontal
U1, U3: IR2011; DIP-8_W7.62mm
U2, U4: LM317_TO-220; TO-220-3_Vertical

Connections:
+36V: C5.1, C6.1, D3.1 (K), D5.1 (K), J5.2, Q1.2 (D), Q3.2 (D), U2.3 (VI), U4.3 (VI)
GND: C1.1, C3.1, C5.2, C6.2, D4.2 (A), D6.2 (A), J5.1, Q2.3 (S), Q4.3 (S), R2.2, R4.2, R_PD2.2, R_PD4.2, U1.7 (COM), U3.7 (COM)
unnamed: C1.2, D1.2 (A), IR2011 VCC_1.1, R1.1, U1.1 (VCC), U2.2 (VO)
unnamed: C2.1, D1.1 (K), U1.2 (VB)
unnamed: C3.2, D2.2 (A), IR2011 VCC_2.1, R3.1, U3.1 (VCC), U4.2 (VO)
unnamed: C4.1, D2.1 (K), U3.2 (VB)
unnamed: C2.2, D3.2 (A), D4.1 (K), M1.1 (+), Q1.3 (S), Q2.2 (D), R_PD1.2, U1.4 (VS)
unnamed: C4.2, D5.2 (A), D6.1 (K), M1.2 (-), Q3.3 (S), Q4.2 (D), R_PD3.2, U3.4 (VS)
unnamed: Q1.1 (G), R_G1.2, R_PD1.1
unnamed: Q2.1 (G), R_G2.2, R_PD2.1
unnamed: Q3.1 (G), R_G3.1, R_PD3.1
unnamed: Q4.1 (G), R_G4.1, R_PD4.1
unnamed: R_G1.1, U1.3 (HO)
unnamed: R_G2.1, U1.8 (LO)
unnamed: R1.2, R2.1, U2.1 (ADJ)
unnamed: R_G3.2, U3.3 (HO)
unnamed: R_G4.2, U3.8 (LO)
unnamed: R3.2, R4.1, U4.1 (ADJ)
PWM_IN1: PC6.1, U1.5 (HIN)
PWM_IN2: PC7.1, U1.6 (LIN)
PWM_IN3: PC8.1, U3.5 (HIN)
PWM_IN4: PC9.1, U3.6 (LIN)

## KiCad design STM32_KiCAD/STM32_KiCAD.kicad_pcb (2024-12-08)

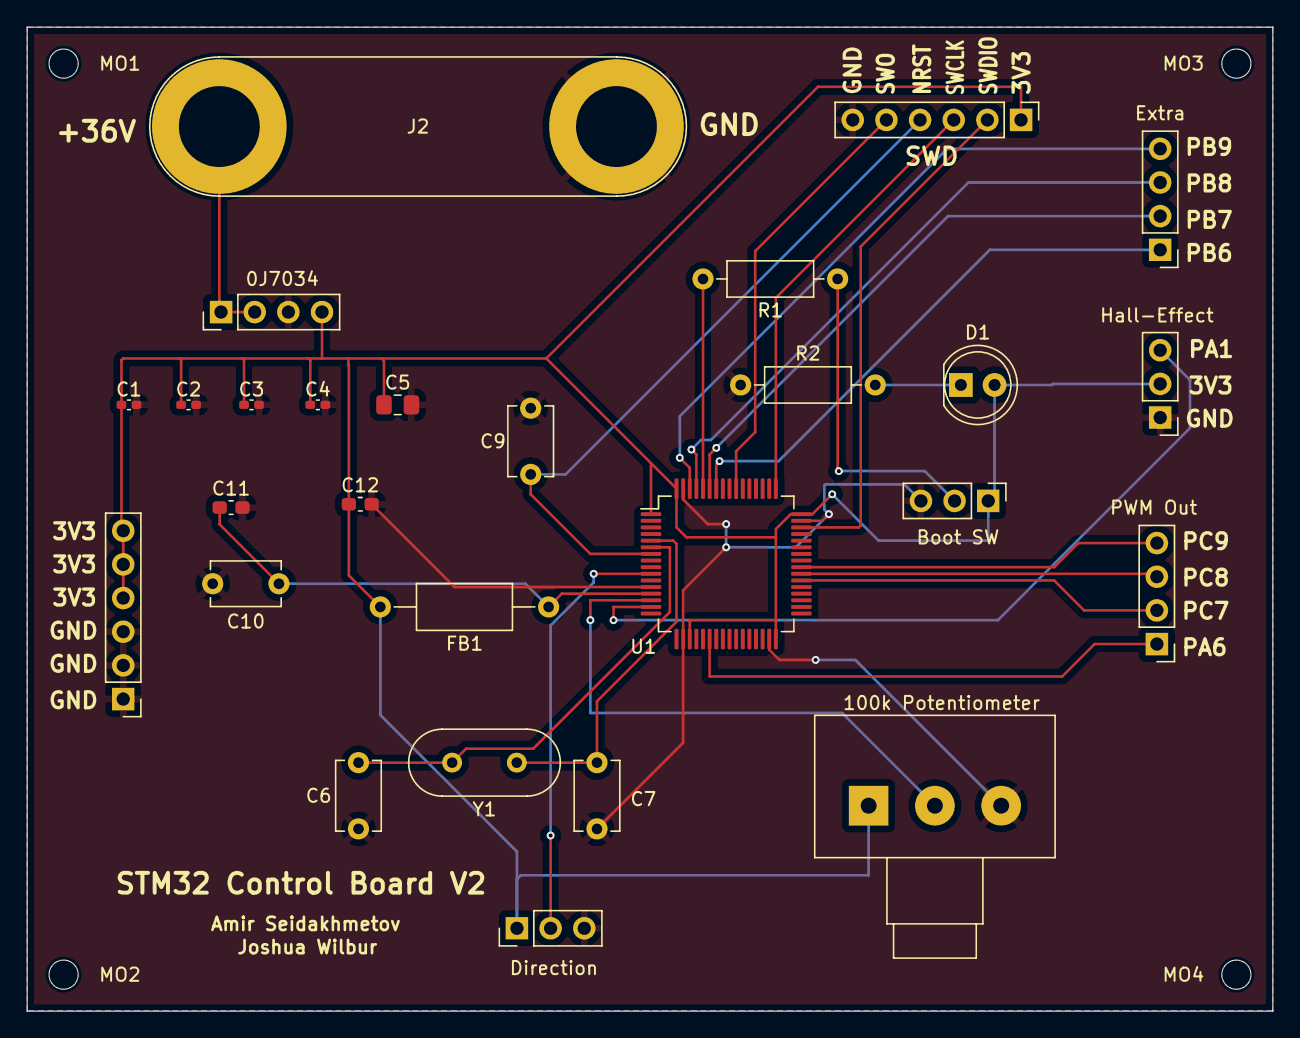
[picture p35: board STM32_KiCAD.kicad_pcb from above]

Board: 2 copper layers, 94.0 x 74.2 mm, 31 parts (0 on the bottom side), 24 nets.

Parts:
0J7034: 0J7034; PinHeader_1x04_P2.54mm_Vertical
100k Potentiometer: 100k; Potentiometer_Alps_RK163_Single_Horizontal
Boot SW: Boot SW; PinHeader_1x03_P2.54mm_Vertical
C1, C2, C3, C4: 0.1u; C_0402_1005Metric_Pad0.74x0.62mm_HandSolder
C5: 4.7u; C_0805_2012Metric_Pad1.18x1.45mm_HandSolder
C6, C7: 20pF; C_Disc_D5.1mm_W3.2mm_P5.00mm
C9: 0.1u; C_Disc_D5.1mm_W3.2mm_P5.00mm
C10: 0.01u; C_Disc_D5.1mm_W3.2mm_P5.00mm
C11, C12: 1u; C_0603_1608Metric_Pad1.08x0.95mm_HandSolder
D1: LED; LED_D5.0mm
Direction: Dir SW; PinHeader_1x03_P2.54mm_Vertical
Extra: Extra; PinHeader_1x04_P2.54mm_Vertical
FB1: 976 Ohm @ 100MHz; L_Axial_L7.0mm_D3.3mm_P12.70mm_Horizontal_Fastron_MICC
Hall-Effect: Hall-Effect Sensor; PinHeader_1x03_P2.54mm_Vertical
J2: Screw_Terminal_01x02; Banana_Jack_2Pin
J6: Power Pins; PinHeader_1x06_P2.54mm_Vertical
MO1, MO2, MO3, MO4: MountingHole_2.2mm_M2
PWM Out: PWM Out; PinHeader_1x04_P2.54mm_Vertical
R1: 10k; R_Axial_DIN0207_L6.3mm_D2.5mm_P10.16mm_Horizontal
R2: 2.2k; R_Axial_DIN0207_L6.3mm_D2.5mm_P10.16mm_Horizontal
SWD: SWD; PinHeader_1x06_P2.54mm_Vertical
U1: STM32L476RG; LQFP-64_10x10mm_P0.5mm
Y1: 8MHz; Crystal_HC49-4H_Vertical

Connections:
+3V3: 0J7034.4, 100k Potentiometer.1, Boot SW.1 (C), C1.1, C2.1, C3.1, C4.1, C5.1, C12.1, D1.2 (A), Direction.1 (C), FB1.2, Hall-Effect.2, J6.4, J6.5, J6.6, SWD.1, U1.1 (VBAT), U1.19 (VDD), U1.32 (VDD), U1.48 (VDDUSB), U1.64 (VDD)
/NRST: C9.1, SWD.4, U1.7 (NRST)
/PWM_1: PWM Out.1, U1.22 (PA6)
/SWCLK: SWD.3, U1.49 (PA14)
/SWDIO: SWD.2, U1.46 (PA13)
/SWO: SWD.5, U1.55 (PB3)
/VIN: 0J7034.1, 0J7034.2, J2.1
GND: 0J7034.3, 100k Potentiometer.3, Boot SW.3 (A), C1.2, C2.2, C3.2, C4.2, C5.2, C6.2, C7.2, C9.2, C10.2, C11.2, C12.2, Direction.3 (A), Hall-Effect.1, J2.2, J6.1, J6.2, J6.3, R2.1, SWD.6, U1.12 (VSSA), U1.18 (VSS), U1.31 (VSS), U1.47 (VSS), U1.63 (VSS)
unnamed: D1.1 (K), R2.2
unnamed: PWM Out.2, U1.38 (PC7)
unnamed: PWM Out.3, U1.39 (PC8)
unnamed: PWM Out.4, U1.40 (PC9)
unnamed: Extra.1, U1.58 (PB6)
unnamed: Extra.2, U1.59 (PB7)
unnamed: Extra.3, U1.61 (PB8)
unnamed: Extra.4, U1.62 (PB9)
unnamed: Boot SW.2 (B), R1.1
unnamed: R1.2, U1.60 (BOOT0)
unnamed: C7.1, U1.5 (PH0), Y1.1
unnamed: C6.1, U1.6 (PH1), Y1.2
unnamed: C10.1, C11.1, FB1.1, U1.13 (VDDA)
PA0_ADC: 100k Potentiometer.2, U1.14 (PA0)
PA1_ADC: Hall-Effect.3, U1.15 (PA1)
PC2_EXTI2: Direction.2 (B), U1.10 (PC2)

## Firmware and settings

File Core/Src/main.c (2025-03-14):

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
/* Includes ------------------------------------------------------------------*/
#include "main.h"

/* USER CODE BEGIN Includes */
#include "H_bridge.h"
#include "user_input.h"
#include "rpm_feedback.h"
#include "stm32l4xx_hal.h"
#include "display_7seg.h"
/* USER CODE END Includes */

ADC_HandleTypeDef hadc1;
ADC_HandleTypeDef hadc2;

I2C_HandleTypeDef hi2c1;

TIM_HandleTypeDef htim2;
TIM_HandleTypeDef htim3;

void SystemClock_Config(void);
static void MX_GPIO_Init(void);
static void MX_TIM3_Init(void);
static void MX_ADC1_Init(void);
static void MX_TIM2_Init(void);
static void MX_ADC2_Init(void);
static void MX_I2C1_Init(void);
/* USER CODE BEGIN 0 */
static int last_update = 0;
int prior_state = -1; // Prior state of the H-Bridge
int prior_hall = 0;
int input_hall = 0; // ADC input value from the hall effect sensor
int pulse_num = 0;
int input_pot = 0;
int feedback_pot = 0; // Input value scaled by feedback
int exp_rpm = 0; // "Expected" RPM of the motor based on the input value
int real_rpm = 0; // Calculated RPM of the motor
int feedback = 0;
/* USER CODE END 0 */

/**
  * @brief  The application entry point.
  * @retval int
  */
int main(void)
{

  /* MCU Configuration--------------------------------------------------------*/

  /* Reset of all peripherals, Initializes the Flash interface and the Systick. */
  HAL_Init();

  /* Configure the system clock */
  SystemClock_Config();

  /* Initialize all configured peripherals */
  MX_GPIO_Init();
  MX_TIM3_Init();
  MX_ADC1_Init();
  MX_TIM2_Init();
  MX_ADC2_Init();
  MX_I2C1_Init();
  /* USER CODE BEGIN 2 */
  // Start clocks for PWM and feedback timing
  HAL_TIM_Base_Start_IT(&htim2); // Begin TIM2 in interrupt mode
  HAL_TIM_PWM_Start(&htim3, TIM_CHANNEL_1); // Begin PWM channels 1-4
  HAL_TIM_PWM_Start(&htim3, TIM_CHANNEL_2);
  HAL_TIM_PWM_Start(&htim3, TIM_CHANNEL_3);
  HAL_TIM_PWM_Start(&htim3, TIM_CHANNEL_4);
  HT16K33_Init(); // Initialize 7 segment display
  PWM_frequency(25000); // Set PWM frequency
  /* USER CODE END 2 */

  /* Infinite loop */
  /* USER CODE BEGIN WHILE */

  // Variables to hold input values and state'


  // Infinite loop for execution
  while(1)
  {
	  // Handle state switching
	  if(prior_state != dir_flag){
		  hbridge_state(0, -1); // All MOSFETs off before transition
		  input_pot = 0;
		  feedback_pot = 0;
		  feedback = 0;
		  HAL_Delay(2000); // 2s dead time if state switches
	  }
	  prior_state = dir_flag;

	  // Use non-blocking SysTick to slow input update, 5ms per update
	  if(HAL_GetTick() - last_update >= 5){
		  input_pot = user_input();
		  feedback_pot = update_input(input_pot, feedback_pot, feedback);

		  // Update the last update time
		  last_update = HAL_GetTick();
	  }

	  // Set H-Bridge state
	  hbridge_state(feedback_pot, dir_flag);

	  // Obtain and interpret hall effect sensor input
	  input_hall = hall_input();
      if (input_hall > 2400 && prior_hall == 0){
    	  pulse_num++;
    	  prior_hall = 1;
      }else if (input_hall < 50 && prior_hall == 1){
    	  pulse_num++;
    	  prior_hall = 0;
      }

      // Every 0.25 seconds, enter this sequence to calculate RPM/apply feedback
	  if(rpm_flag == 1){
		  rpm_flag = 0;
		  real_rpm = hall_rpm(pulse_num);
		  pulse_num = 0;
		  HT16K33_DisplayInteger(real_rpm); // Display measured RPM on 7 segment
		  exp_rpm = input_to_rpm(input_pot);
		  feedback = closed_loop_feedback(exp_rpm, real_rpm);
	  }
    /* USER CODE END WHILE */

    /* USER CODE BEGIN 3 */
  }
  /* USER CODE END 3 */
}

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


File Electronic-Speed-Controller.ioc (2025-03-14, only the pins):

Mcu.UserName=STM32L476RGTx
PA0.Signal=ADCx_IN5
PA1.Signal=ADCx_IN6
PA6.Signal=S_TIM3_CH1
PB6.Signal=I2C1_SCL
PB7.Signal=I2C1_SDA
PC1.Signal=GPXTI1
PC2.Signal=GPXTI2
PC7.Signal=S_TIM3_CH2
PC8.Signal=S_TIM3_CH3
PC9.Signal=S_TIM3_CH4

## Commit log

2024-05-03 basic LED blinking program
2024-07-11 Updated .ioc file to add PWM capability
2024-07-16 H-Bridge state program added, allows clockwise/coclockwise motor rotation
2024-07-19 test commit to fix issue
    [Electronic-Speed-Controller.ioc]
2024-07-23 Fine tuned PWM frequency to 25kHz
2024-08-03 Added image of H Bridge prototype (v1)
2024-08-20 Added H-bridge circuit schematic (V2)
2024-09-08 add updated schematic with bypass caps
2024-09-12 setup for EXTI1 interrupt complete
2024-09-13 create interrupts for pulse counting and RPM processing
2024-09-16 created function for adjusting PWM frequency, needs testing
2024-09-17 complete PWM frequency function
2024-09-20 debugged pulse counting interrupts
    [Electronic-Speed-Controller Debug.cfg]
2024-09-20 add dead time and interrupt for switching motor direction
2024-09-21 Upload ESC schematic v1.0
2024-09-21 reset unused GPIO pins
    [Electronic-Speed-Controller.ioc, main.c]
2024-09-23 set up ADC for DMA
2024-09-23 more work done on ADC, TODO fix ADC1_CH1 output
    [Electronic-Speed-Controller.ioc, main.c]
2024-09-24 some debugging on the ADC channel, changed pins
2024-09-25 switch ADC inputs to use polling
2024-09-25 remove DMA code, clean up comments
2024-10-08 new schematic revision
    revised high side mosfet pull downs to attach to source instead of ground. modified flyback diodes, other ones are too small
2024-10-08 small update to schematic v4
    added power and pin connectors
2024-10-09 clean up files, build framework for feedback code
2024-10-15 hall effect RPM function working
2024-10-23 upload version 5 of ESC schematic
    mostly resistor value changes, updated diode on gate driver to reflect prototype
2024-10-25 fine tune hall effect RPM code
2024-10-30 limit speed to prevent inductive kickback
    [H_bridge.c]
2024-11-01 upload STM32 control board schematic
2024-11-08 implemented feedback code, reworked user input as well
    [H_bridge.c, main.c, rpm_feedback.c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]
2024-11-13 Battery sensing
    adding initial battery sensing
2024-11-13 finished fixing user input, switch PC6 to PA6
    [Electronic-Speed-Controller.ioc, H_bridge.c, main.c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]
2024-11-15 upload H-Bridge schematic v6
2024-11-16 set PB3 as SWO pin
2024-11-16 upload STM32 schematic V2
2024-11-18 update code to account for geared down motor
2024-11-19 revise schematic v6 to add battery protection
2024-11-20 limit input range from 60-200 RPM, further tune feedback
2024-11-25 Adding first version of PID feedback control
    Preliminary execution of PID feedback control
2024-12-04 MIN_INPUT adjustment + PID
    Adjusting MIN_INPUT variable to match 60rpm due to changed resistors - verified imperially by adjusting the value and measuring minimum rpm of the motor until it reaches ~60
    Changing PID constants to global variables for troubleshooting
2024-12-05 Finish PID variable tuning, re-add code that got lost
2024-12-05 tune PID for 36V
2024-12-06 changed RPM sampling time to 0.25s, further tuned PID
2024-12-08 Upload PCB files, clean up code and add comments
    [H_Bridge_KiCAD-B_Cu.gbl, H_Bridge_KiCAD-B_Mask.gbs, H_Bridge_KiCAD-B_Paste.gbp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]
2024-12-11 update schematics to match current circuit
2024-12-14 increased Kp and modified hall effect bounds
2024-12-15 upload revised STM32 schematic
    Buck converter IC failed on Friday, this schematic has a new voltage step down method
2024-12-15 fix errors on schematic
2025-03-09 updated schematics to reflect current circuit + corrections
2025-03-11 update H-bridge schematic after feedback
